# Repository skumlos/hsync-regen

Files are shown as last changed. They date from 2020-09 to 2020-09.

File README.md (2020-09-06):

HSYNC Re-generation circuit

This circuit is based on (and very close to being a 100% copy of) Renesas Technical Brief 476
(tb476) associated with the ISL59885 sync-separator IC.

The basic idea is that some sync signals (looking at you SEGA Master System) do not adhere to
"proper" sync waveform, mainly meaning that during VSYNC, HSYNC is completely missing. This
will usually show itself as a "skew" in the top (or even more) of the video image, as the PLL
circuit of the monitor loses lock to the horizontal sync, and has to re-acquire it after each
vertical sync. To avoid this, creating a re-generated horizontal sync signal, derived from
the original, but ever-present, is the key. This circuit does this completely through discrete
components, and at the same time allows for HVSYNC, as the ISL59885 outputs both HSYNC and
VSYNC as separate signals. Should work for both CSYNC and Sync-on-Green (Y of YPbPr) signals
(latter untested).

This should be especially useful for monitors that show (excessive) flagging (like Sony BVM-A,
BVM D9/D14 or JVC DT-V monitors).

Jumper descriptions (looking at component side, BNC outputs to right):

JP2 Input is 75 Ohm terminated (down) or not (up).

JP3 Source signal is passed directly to the output (up) or the sync stripped version (down).

JP4 HSYNC output is HSYNC (right) or CSYNC (including the regenerated HSYNC) (left).

For a complete description, read the technical brief, which is available on Renesas' website
under "Documents" section for the ISL59885.

Attach CSYNC (or Y/G) to the input, and connect HSYNC and VSYNC to monitor (or JP4 set to CSYNC
and then HSYNC (now CSYNC) to monitor sync input). Board needs to powered by 5V from USB or
through J6.

(2020) Martin Hejnfelt (martin@hejnfelt.com)

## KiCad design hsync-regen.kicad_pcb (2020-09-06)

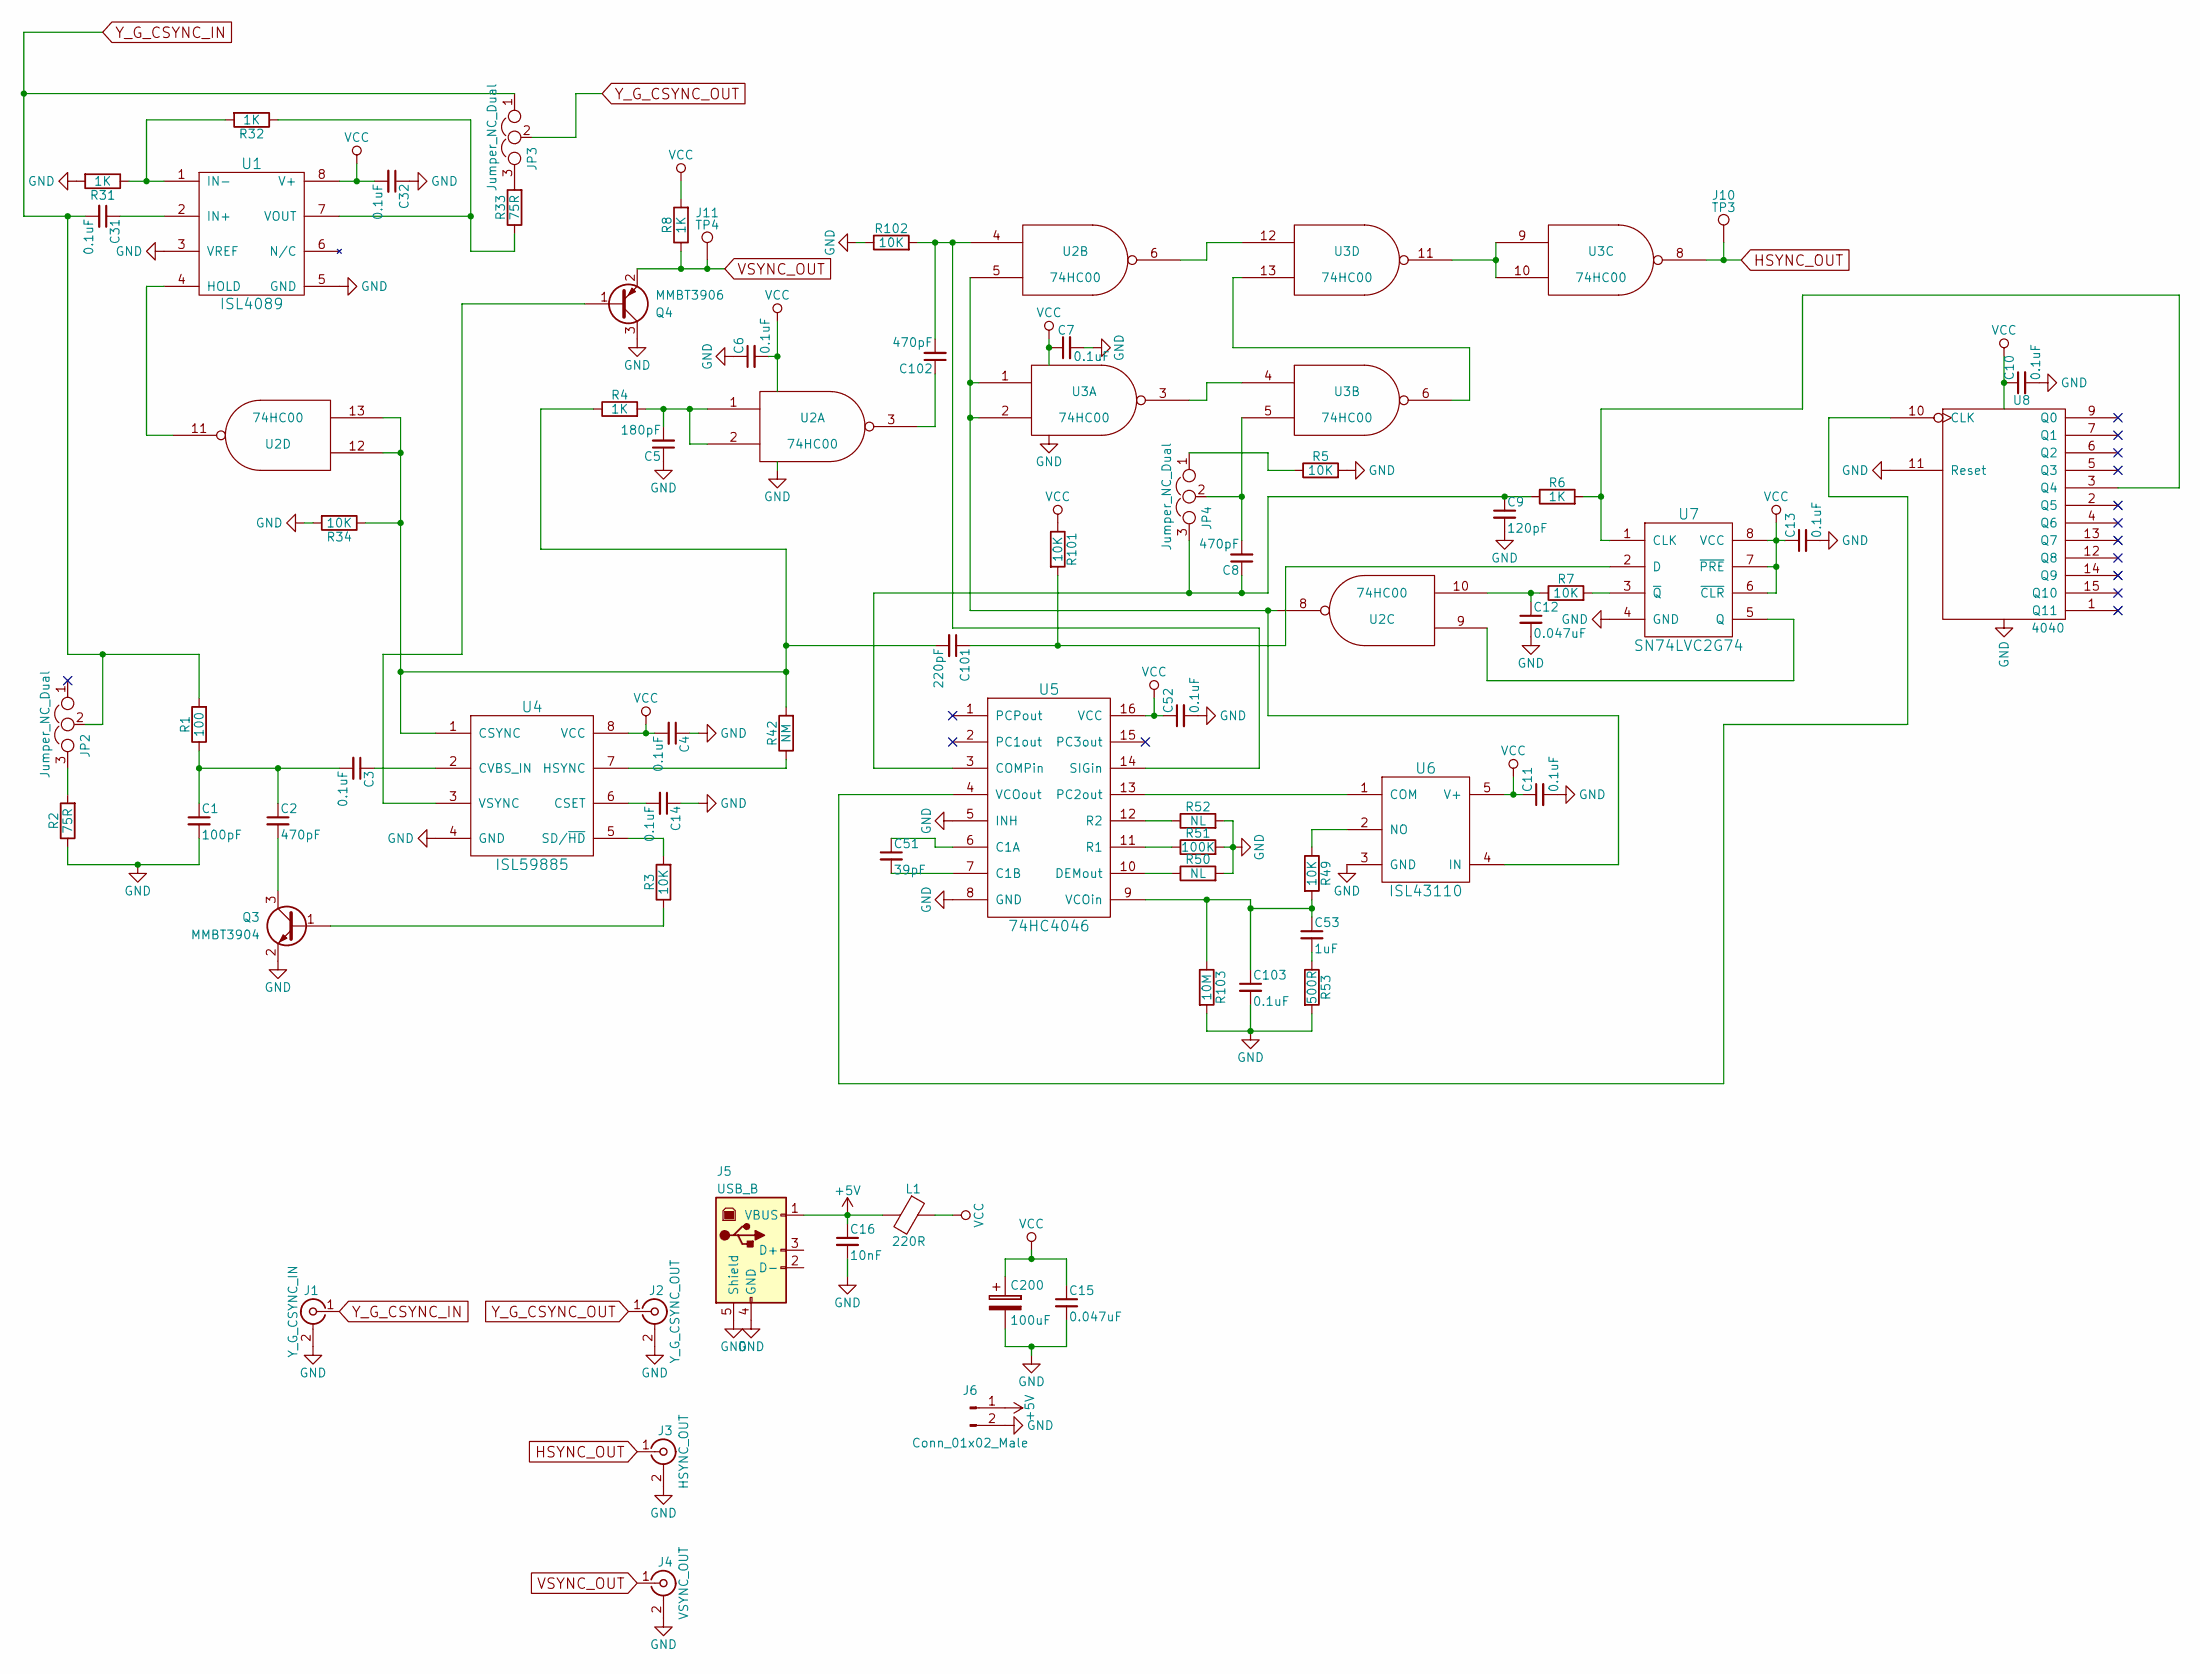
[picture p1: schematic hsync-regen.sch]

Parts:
C1: 100pF; C_0805_HandSoldering
C2, C8, C102: 470pF; C_0805_HandSoldering
C3, C4, C6, C7, C10, C11, C13, C14, C31, C32, C52, C103: 0.1uF; C_0805_HandSoldering
C5: 180pF; C_0805_HandSoldering
C9: 120pF; C_0805_HandSoldering
C12, C15: 0.047uF; C_0805_HandSoldering
C16: 10nF; C_0805_HandSoldering
C51: 39pF; C_0805_HandSoldering
C53: 1uF; C_0805_HandSoldering
C101: 220pF; C_0805_HandSoldering
C200: 100uF; CP_Elec_6.3x5.3
J1: Y_G_CSYNC_IN; BNC-THT
J2: Y_G_CSYNC_OUT; BNC-THT
J3: HSYNC_OUT; BNC-THT
J4: VSYNC_OUT; BNC-THT
J5: USB_B; USB_Micro-B
J6: Conn_01x02_Male; Pin_Header_Straight_1x02_Pitch2.54mm
J10: TP3; Measurement_Point_Round-SMD-Pad_Big
J11: TP4; Measurement_Point_Round-SMD-Pad_Big
JP2, JP3, JP4: Jumper_NC_Dual; Pin_Header_Straight_1x03_Pitch2.54mm
L1: 220R; R_0805_HandSoldering
Q3: MMBT3904; SOT-23_Handsoldering
Q4: MMBT3906; SOT-23_Handsoldering
R1: 100; R_0805_HandSoldering
R2, R33: 75R; R_0805_HandSoldering
R3, R5, R7, R34, R49, R101, R102: 10K; R_0805_HandSoldering
R4, R6, R8, R31, R32: 1K; R_0805_HandSoldering
R42: NM; R_0805_HandSoldering
R50, R52: NL; R_0805_HandSoldering
R51: 100K; R_0805_HandSoldering
R53: 500R; R_0805_HandSoldering
R103: 10M; R_0805_HandSoldering
U1: ISL4089; SOIC-8_3.9x4.9mm_Pitch1.27mm
U2, U3: 74HC00; TSSOP-14_4.4x5mm_Pitch0.65mm
U4: ISL59885; SOIC-8_3.9x4.9mm_Pitch1.27mm
U5: 74HC4046; TSSOP-16_4.4x5mm_Pitch0.65mm
U6: ISL43110; SOT-23-5
U7: SN74LVC2G74; VSSOP-8_2.3x2mm_Pitch0.5mm
U8: 4040; TSSOP-16_4.4x5mm_Pitch0.65mm

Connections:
+5V: C16.1, J5.1 (VBUS), J6.1, L1.2
GND: C1.2, C4.1, C5.1, C6.1, C7.2, C9.2, C10.2, C11.2, C12.2, C13.2, C14.1, C15.2, C16.2, C32.1, C52.2, C103.2, C200.2, J1.2 (Ext), J2.2 (Ext), J3.2 (Ext), J4.2 (Ext), J5.4 (GND), J5.5 (Shield), J6.2, Q3.2 (E), Q4.3 (C), R2.1, R5.2, R31.2, R34.2, R50.2, R51.2, R52.2, R53.2, R102.1, R103.2, U1.3 (VREF), U1.5 (GND), U2.7 (GND), U3.7 (GND), U4.4 (GND), U5.5 (INH), U5.8 (GND), U6.3 (GND), U7.4 (GND), U8.8 (VSS), U8.11 (Reset)
HSYNC_OUT: J3.1 (In), J10.1, U3.8
unnamed: C1.1, C2.1, C3.2, R1.1
unnamed: C2.2, Q3.3 (C)
unnamed: C3.1, U4.2 (CVBS_IN)
unnamed: C5.2, R4.2, U2.1, U2.2
unnamed: C8.1, C9.1, JP4.3, R6.1, U5.3 (COMPin)
unnamed: C8.2, JP4.2, U3.5
unnamed: C12.1, R7.1, U2.10
unnamed: C14.2, U4.6 (CSET)
unnamed: C31.1, U1.2 (IN+)
unnamed: C51.1, U5.6 (C1A)
unnamed: C51.2, U5.7 (C1B)
unnamed: C53.2, R53.1
unnamed: C101.1, R101.2, U7.2 (D)
unnamed: C101.2, R4.1, R34.1, R42.2, U2.12, U2.13, U4.1 (CSYNC)
unnamed: C102.1, U2.3
unnamed: C102.2, R102.2, U2.4, U5.14 (SIGin)
unnamed: C53.1, C103.1, R49.2, R103.1, U5.9 (VCOin)
unnamed: JP2.3, R2.2
unnamed: JP3.3, R33.2
unnamed: JP4.1, R5.1
unnamed: Q3.1 (B), R3.1
unnamed: Q4.1 (B), U4.3 (VSYNC)
unnamed: R3.2, U4.5 (SD/~HD)
unnamed: R6.2, U7.1 (CLK), U8.3 (Q4)
unnamed: R7.2, U7.3 (~Q)
unnamed: R31.1, R32.2, U1.1 (IN-)
unnamed: R32.1, R33.1, U1.7 (VOUT)
unnamed: R42.1, U4.7 (HSYNC)
unnamed: R49.1, U6.2 (NO)
unnamed: R50.1, U5.10 (DEMout)
unnamed: R51.1, U5.11 (R1)
unnamed: R52.1, U5.12 (R2)
unnamed: U1.4 (HOLD), U2.11
unnamed: U2.5, U2.8, U3.1, U3.2, U6.4 (IN)
unnamed: U2.6, U3.12
unnamed: U2.9, U7.5 (Q)
unnamed: U3.3, U3.4
unnamed: U3.9, U3.10, U3.11
unnamed: U3.6, U3.13
unnamed: U5.4 (VCOout), U8.10 (CLK)
unnamed: U5.13 (PC2out), U6.1 (COM)
VCC: C4.2, C6.2, C7.1, C10.1, C11.1, C13.1, C15.1, C32.2, C52.1, C200.1, L1.1, R8.2, R101.1, U1.8 (V+), U2.14 (VCC), U3.14 (VCC), U4.8 (VCC), U5.16 (VCC), U6.5 (V+), U7.6 (~CLR), U7.7 (~PRE), U7.8 (VCC), U8.16 (VDD)
VSYNC_OUT: J4.1 (In), J11.1, Q4.2 (E), R8.1
Y_G_CSYNC_IN: C31.2, J1.1 (In), JP2.2, JP3.1, R1.2
Y_G_CSYNC_OUT: J2.1 (In), JP3.2

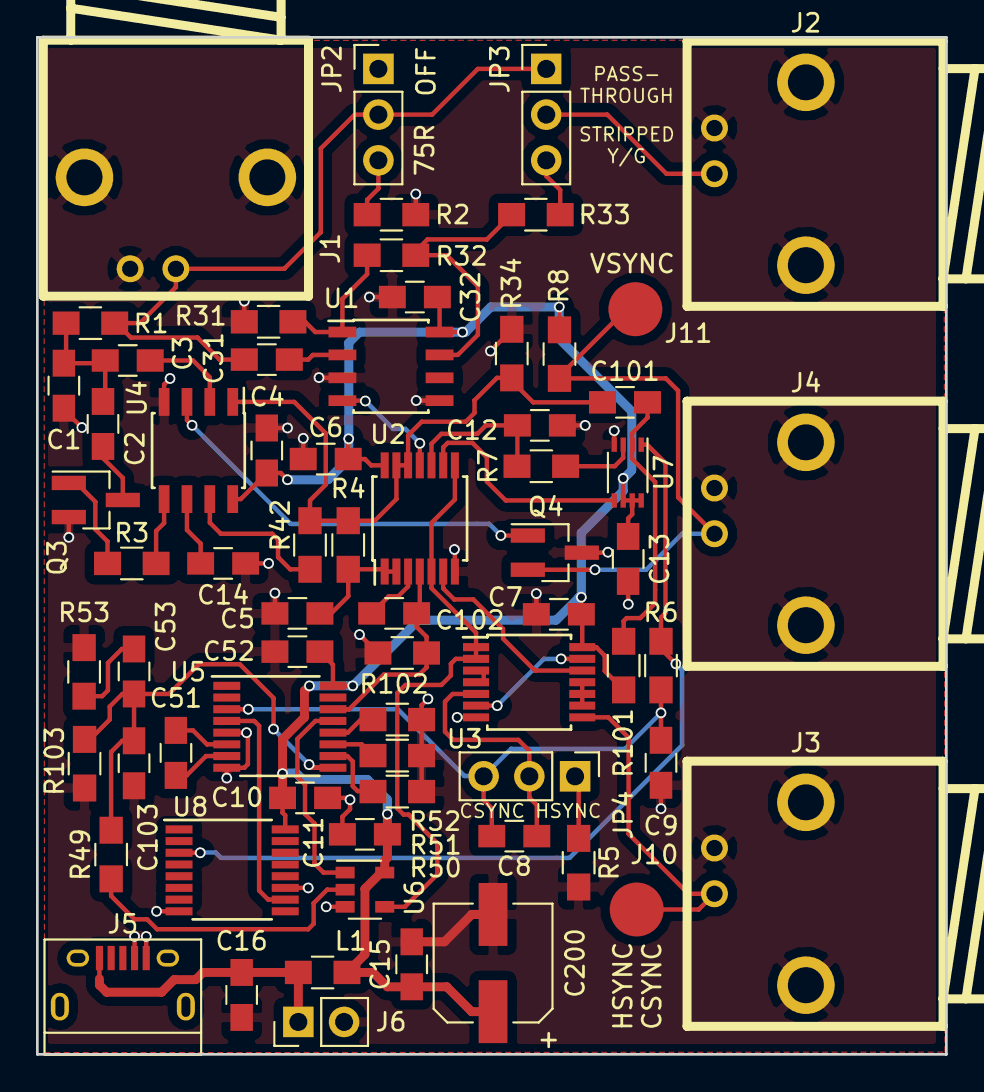
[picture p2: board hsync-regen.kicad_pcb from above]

Board: 2 copper layers, 50.5 x 56.5 mm, 68 parts (0 on the bottom side), 48 nets.
